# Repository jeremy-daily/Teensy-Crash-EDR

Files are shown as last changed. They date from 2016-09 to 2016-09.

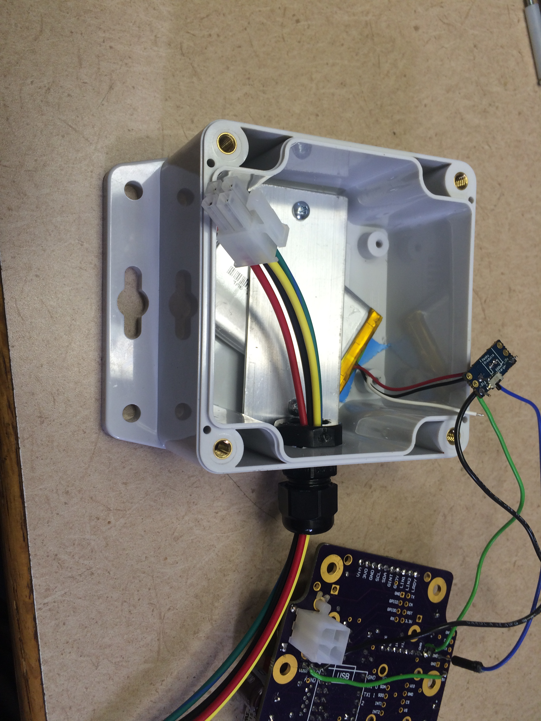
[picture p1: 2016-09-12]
docs/images/2016-09-09 13.49.59.jpg

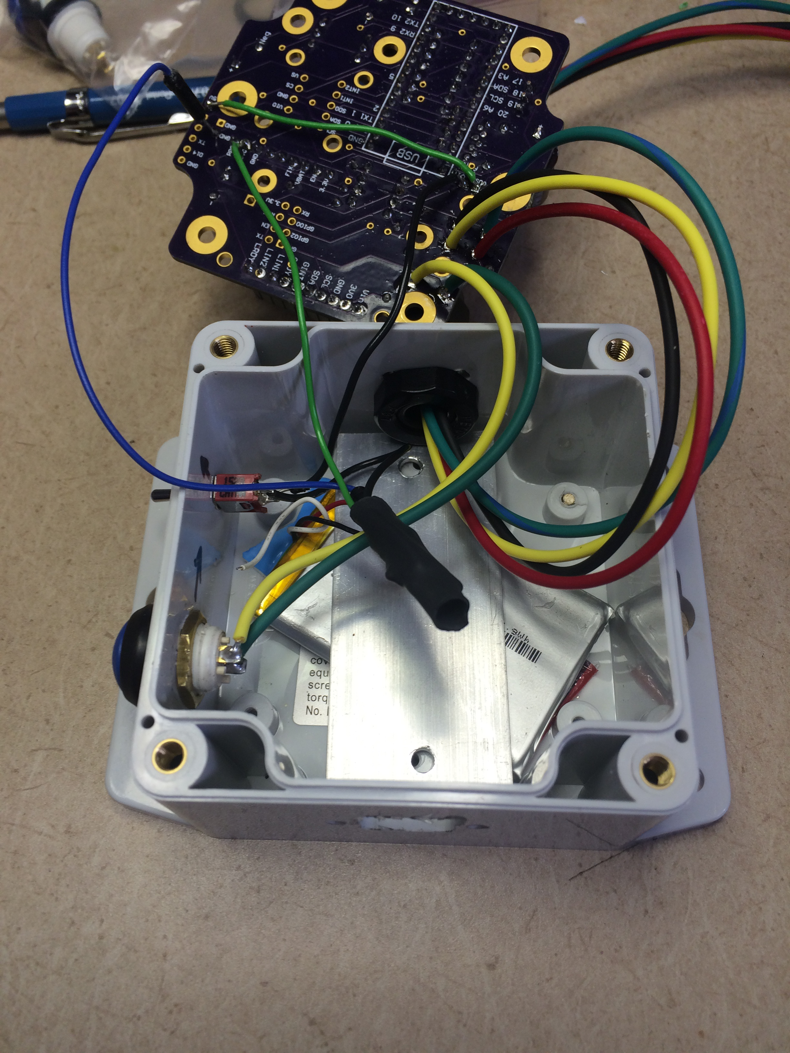
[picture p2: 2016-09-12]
docs/images/2016-09-09 15.58.58.jpg

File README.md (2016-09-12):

# Teensy-Crash-EDR
A Teensy 3.2 based through hole project that includes CAN, SD, GPS, Wireless, and Accelerometers.

CAUTION: This device is not intended to be used on public roadways. Connecting this device to a CAN bus may affect the operation of a vehicle or piece ofe equipment. If you decide to use the device and any code or derivatives, then anything bad that happens is your fault. Please use these resources responsibly.

The project website is https://jeremy-daily.github.io/Teensy-Crash-EDR/

## Project Purpose
The goal of this project is to design and share an open source data acquisition device that can be used for vehicle crash testing. The crash tests
considered are typically done at crash reconstruction conferences or trainig events where law enforcement and private crash investigators
gather to witness a crash and solidify their understanding of the dynamics involved with such an event. 

Additionally, a light version (the one without the sensors) is designed to be used in training on Controller Area Networks and J1939.

## Hardware Features
 * Microprocessor: Teensy 3.2 32-bit ARM-Cortex M4 Arduino compatible microprocessor board
 * MicroSD Card for storage (Tested to log data at 4000Hz)
 * GPS: Adafruit Ultimate GPS capable of 10Hz update rates
 * High Speed CAN (1Mbps) capable of processing 100% bus load
 * Real Time Clock
 * High G Tri-axial accelerometer (+/- 200G)
 * Low G Tri-axial Accelerometer
 * Tri-axial Rate Gyro
 * Tri-axial Magnetometer
 * Battery Powered (Charges with USB)
 * Wi-Fi Capable (Internet of Things)
 * 7-36 VDC input with reverse polarity protection
 * Open source design and easily obtainable parts (See Hardware and Schematics directory)
 * Low cost
 * All through hole parts so it can be easily hand soldered.

## Learning to Write Software
The idea of this project is to enable students to start from the beginning and succeed with little or no previous experience with writing code for embedded processors.
There are a couple of prerequisites: 
 1. Arduino software (the code was developed and tested with version 1.6.11)
 2. Teensyduino software, which is an extension of Arduino (the code was developed and tested and developed with v1.30)
 3. The SdFat Arduino library
The idea of the code development is to take examples that are close to the functionality of what you are interested in and adapt them to the hardware we have. As such, some of the examples and projects have different
programming styles. This is because those programs extend the code base from different sources. 

The following sections describe the functional and learning objectives of each of the enumerated examples in this repository. They example programs (sometimes called sketches) are intended to be used in sequence. The assignment is to extend
the functionality of each of the code bases to demonstrate the learning objectives. 

### Lesson 1: Blink
This is a basic program that helps the student understand the process of writing a program and uploading it to the processor to run. The objective is to be able to change the blink rate and see the result.

Assignment: Change the Blink Rate by using an elapsedMillis timer.
### Lesson 2: Receive CAN messages
Introduce the FlexCAN library and print the CAN messages to the serial output.

Assignment: Change the output format to be comma separated values
### Lesson 3: Real Time Clock
Add the time keeping libraries so CAN messages can be timestamped with the real time
 
Assignment: Add the microseconds to each real time stamp. (Hint: You can use an IntervalTimer to reset an elapsedMicros counter every second.)

### Lesson 4: Send Request Messages for J1939
Add the ability to broadcast request messages for different J1939 parameters. Some data is only available upon request.

Assignment: Send requests to different Destination Addresses. Add another PGN to request to the list.
### Lesson 5: Interpret Simple J1939 Messages
Using the J1939-71 or J1939-DA interpret some interesting messages, like wheel speed.

Assignment: Add interpreters for a couple other signals of interest (e.g. Engine RPM or Front Axle Speed)
### Lesson 6: Write data to an SD Card
Log all CAN traffic to an SD Card.

Assignment: Send request messages so the responses get logged.

## Future Work
### Lesson 7: Add GPS data to the SD log files (to be written)
 
### Lesson 8: Read Sensor Data (to be written)

### Lesson 9: Implement an Extended Kalman Filter (to be written)

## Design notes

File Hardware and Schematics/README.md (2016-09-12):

#Teensy 3.2 Based Crash EDR Hardware
This repository contains the information needed to understand how the device is built. The schematic provides the data needed to program 
the different input and output pins. The Bill of Materials is comprehsive in that it includes the parts for the circuit card assembly as well as the additional parts.
##Errata
 1. The 5V0 net and Vin need to be connected. This must be done by soldering an extra jumper wire between those pins. This modification is required for CAN to work.
 2. The Adafruit Ultimate GPS module has a 3.3V regulator and can provide power to the board if it is installed. However, the 3.3V line from the GPS headers is not connected, so it needs to have a jumper connected.
 3. The A14 voltage monitor is not connected, so R4 and R5 are not needed. Alternatively, they could be connected by hand. However, this feature is not that interesting.
 4. The silkscreen on the power and CAN entry cables have CANH and CANL backwards. In other words, the yellow CANH wire should be soldered to the bottom side into the CANH labeled hole. This only applied to the Rev2 boards.
## Minimum Assembly
For interfacing with CAN and creating a CAN logger to work with cars and trucks, you do not need the following:
 * 9-DOF IMU breakout board
 * 200G Triaxial Accelerometer
 * ESP8266 Wifi
 * Battery and Battery Charger
 
## Assembly Notes
 * Mount the voltage regulator on the bottom of the board.
 * Use long pinned female headers for the 7 holes hear the USB port on the Teensy 3.2. This enables a battery charger to be placed in line with the Teensy 3.2 under the board.
 * The 9-DOF board needs to be mounted on the bottom to ensure clearance for the USB cable.
 * The values of the electrolytic capacitors can be anywhere from 22uF to 400uF.
 * The four wires that go out of the box should be soldered to the bottom of the board. It is recommended that this be one of the last steps.
 * Be sure to tap the M3 holes in the Bud Box so the brass standoffs don't snap off when tightening. 
 
### Other Notes
 * The Wireless module is untested as of September 2016. Please let me know if this works.
 * The accelerometers (9DOF and High-G) are also untested. Please let me know if they work.

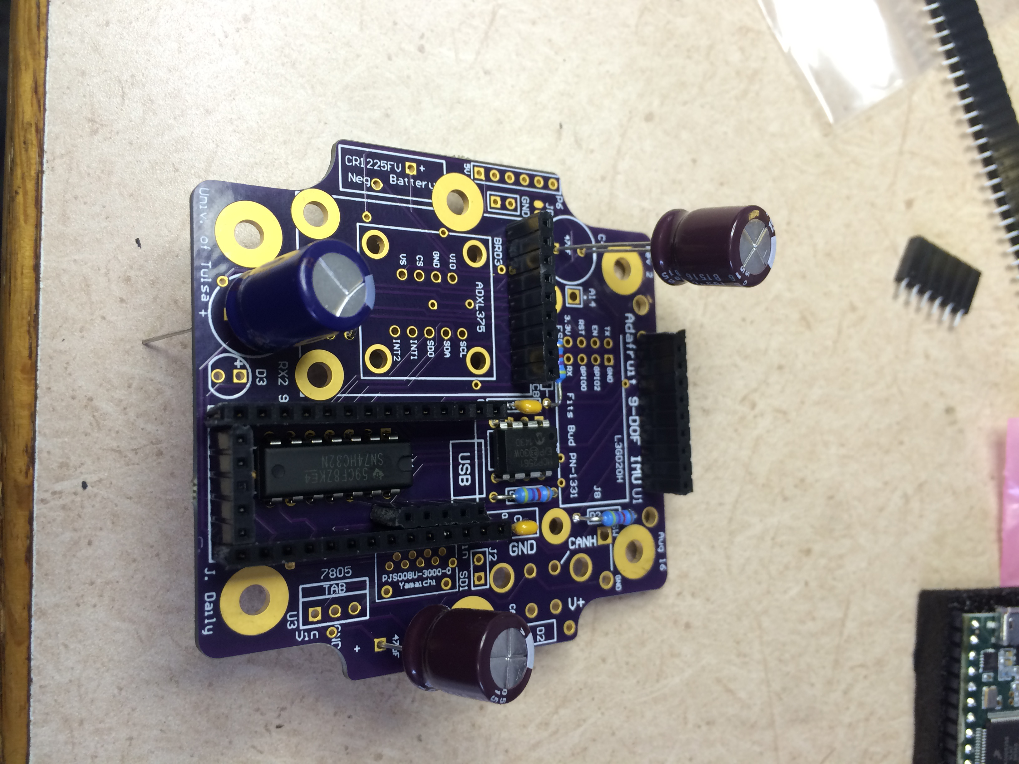
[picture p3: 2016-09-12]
docs/images/2016-09-08 16.24.32.jpg

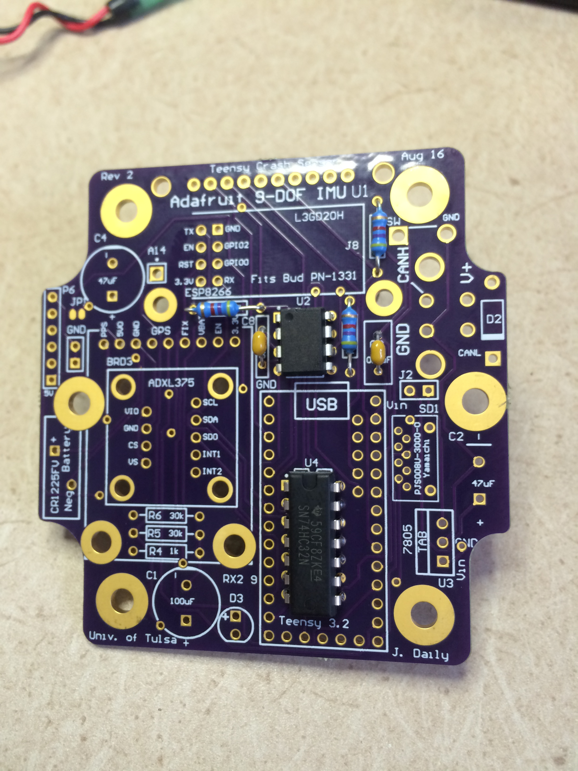
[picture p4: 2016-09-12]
docs/images/2016-09-08 16.00.48.jpg

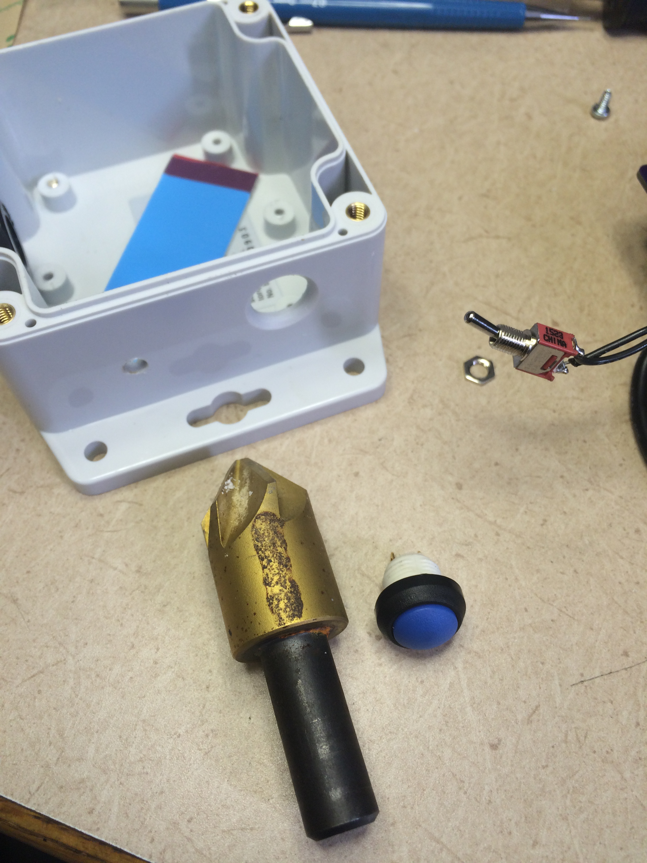
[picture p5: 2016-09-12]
docs/images/2016-09-09 14.00.34.jpg

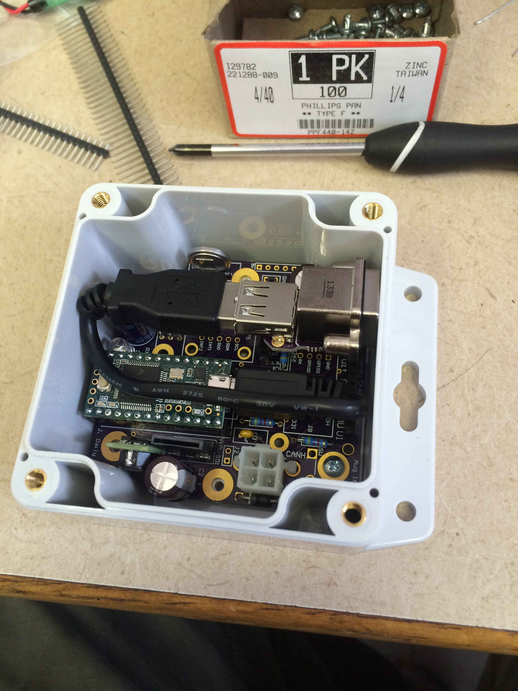
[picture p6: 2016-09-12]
docs/images/2016-09-08 16.52.31.jpg

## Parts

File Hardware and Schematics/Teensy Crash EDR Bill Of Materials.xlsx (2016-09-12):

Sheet: Top Level Assembly
Qty | Designator | Description | Manufacturer | Manufacturer Part Number | Supplier | Supplier Part Number | Unit Cost | Total Cost
1 | CCA | Teensy Crash Sensor Circuit Card Assembly | Self Assembled |  | See BOM |  | $38.97 | $38.97
1 | Cable1 | 6 inch Micro USB cable | StarTech | UUSBHAUB6 | Amazon | B003YKX6WM | $2.79 | $2.79
1 | Battery | 3.7V 1100mAh 432770 Lithium Polymer Li-Po Rechargeable Battery For DIY Mp3 MP4 MP5 GPS | Ofeely | 432770 | Amazon | B016ZU9C70 | $12.99 | $12.99
1 | Foam | 1/16" White Double Sided Acrylic Adhesive Polyethylene Foam Tape With Blue Poly Liner | Mr. Tape | Unknown | Amazon | B01H3ZULM6 | $0.07 | $0.07
1 | Sdcard | Samsung 16GB PRO Class 10 Micro SDHC Card with Adapter up to 90MB/s | Samsung | Unknown | Amazon | MB-MG16EA/AM | $10.99 | $10.99
1 | Wire,Blk | Automotive Primary Wire GXL-20, Cond: 7/28 (units are in feet) | Allied Wire and Cable | GXL-20 | awcwire.com | GXL-20 Black | $0.20 | $0.20
1 | Wire,Grn | Automotive Primary Wire GXL-20, Cond: 7/28 (units are in feet) | Allied Wire and Cable | GXL-20 | awcwire.com | GXL-20 Green | $0.20 | $0.20
1 | Wire,Red | Automotive Primary Wire GXL-20, Cond: 7/28 (units are in feet) | Allied Wire and Cable | GXL-20 | awcwire.com | GXL-20 Red | $0.20 | $0.20
1 | Wire,Yel | Automotive Primary Wire GXL-20, Cond: 7/28 (units are in feet) | Allied Wire and Cable | GXL-20 | awcwire.com | GXL-20 Yellow | $0.20 | $0.20
1 | USB2 | USB - A Receptacle Connector 4 Position Through Hole, Right Angle, Horizontal | On shore Technology | USB-A1HSW6 | Digikey | ED2989-ND | $0.48 | $0.48
0 | BRD2 (alt) | Adafruit 9-DOF IMU Breakout - L3GD20H + LSM303 PRODUCT ID: 1714 | Adafruit Industries LLC | 1714 | Digi-Key | 1528-1029-ND | $19.95 | $0.00
1 | GPS | Adafruit ultimate GPS breakout board | Adafruit Industries LLC | 746 | Digi-Key | 1528-1153-ND | $39.95 | $39.95
0 | ADXL375 (alt) | Analog Devices Accelerometer Evaluation Board | Analog Devices Inc. | EVAL-ADXL375Z | Digi-Key | EVAL-ADXL375Z-ND | $37.50 | $0.00
1 | Holder | 1/16" x 1" x 3" Aluminum strap with holes for the Battery Holder | Self cut and drilled | Unknown | McMaster-Carr | 8975K196 | $0.20 | $0.20
0 | HolderScrews | Pan Head Phillips Screw for Sheet Metal Zinc-Plated Steel, Number 4 Size, 5/16" Length | McMaster-Carr | 90190A107 | McMaster-Carr | 90190A107 | $0.02 | $0.00
2 | HolderScrews (alt) | Thread-Cutting Screw for Metal & Plastic (Type F) Pan Head Phillips, Zinc-Plated Steel, 4-40 Thread, 1/4" Long | McMaster-Carr | 90087A106 | McMaster-Carr | 90087A106 | $0.07 | $0.13
4 | PCB screw | Thread-Cutting Screw for Metal & Plastic (Type F) Pan Head Phillips, Zinc-Plated Steel, 4-40 Thread, 1/2" Long | McMaster-Carr | 90087A108 | McMaster-Carr | 90087A108 | $0.07 | $0.29
0 | PCB screw (alt) | Pan Head Phillips Screw for Sheet Metal Zinc-Plated Steel, Number 4 Size, 1/2" Length | McMaster-Carr | 90190A110 | McMaster-Carr | 90190A110 | $0.02 | $0.00
4 | ADXL Screw | Zinc-Plated Steel Pan Head Phillips Machine Screw 2-56 Thread, 5/16" Length | McMaster-Carr | 90272A078 | McMaster-Carr | 90272A078 | $0.03 | $0.13
6 | BoardScrew | Zinc-Plated Steel Pan Head Phillips Machine Screw 2-56 Thread, 5/8" Length | McMaster-Carr | 90272A083 | McMaster-Carr | 90272A083 | $0.09 | $0.52
0 | Nut1 | Low-Strength Steel Nylon-Insert Locknut Zinc-Plated, 2-56 Thread Size, 1/4" Wide, 9/64" High | McMaster-Carr | 90631A003 | McMaster-Carr | 90631A003 | $0.03 | $0.00
10 | Nut1 (alt) | Low-Strength Steel Thin Nylon-Insert Locknut Zinc-Plated, 2-56 Thread, 1/4" Wide, 7/64" High | McMaster-Carr | 90633A004 | McMaster-Carr | 90633A004 | $0.08 | $0.79
2 | USBScrews | Black-Oxide Finish Pan Head Phillips Machine Screw 18-8 Stainless Steel, 4-40 Thread, 3/8" Length | McMaster-Carr | 91249A108 | McMaster-Carr | 91249A108 | $0.04 | $0.08
4 | Spacer3 | Nylon Unthreaded Spacers 3/16" OD, 1/8" Length, for Number 2 Screw Size | McMaster-Carr | 94639A701 | McMaster-Carr | 94639A701 | $0.07 | $0.28
4 | Spacer1 | Nylon Unthreaded Spacers 3/16" OD, 1/4" Length, for Number 4 Screw Size | McMaster-Carr | 94639A706 | McMaster-Carr | 94639A706 | $0.08 | $0.30
6 | Spacer2 | Nylon Unthreaded Spacers 3/16" OD, 7/16" Length, for Number 2 Screw Size | McMaster-Carr | 94639A711 | McMaster-Carr | 94639A711 | $0.08 | $0.49
1 | ADXLPins | 64 Position Receptacle Connector 0.100" (2.54mm) Through Hole Gold | Mill-Max | 311-43-164-41-001000 | Mouser | 575-31143164 (http://www.mouser.com/Search/ProductDetail.aspx) | $5.34 | $5.34
1 | BRD2 | Multiple Function Sensor Development Tools L3GD20H + LSM303 IMU Breakout | Adafruit | 1714 | Mouser | 485-1714 | $19.95 | $19.95
1 | PSW | Power Switch Toggle Switches Solder Lug Slvr SP Off-None-On TS | TE Connectivity | TMS6T3B1M1QE (http://www.mouser.com/Search/ProductDetail.aspx) | Mouser | 506-TMS6T3B1M1QE | $5.19 | $5.19
2 | Headers | Headers & Wire Housings FULL STICK HDR/36POS | 3M | 929834-01-36-RK | Mouser | 517-929834-01-36-RK | $1.58 | $3.16
1 | TeensyPins, 5Pos | Tall Headers & Wire Housings .100 STR 5 PIN .235-.410 | 3M | 929834-03-05-RK (http://www.mouser.com/ProductDetail/3M-Electronic-Solutions-Division/929834-03-05-RK/) | Mouser | 517-929834-03-05-RK (http://www.mouser.com/ProductDetail/3M-Electronic-Solutions-Division/929834-03-05-RK/) | $0.66 | $0.66
1 | TeensyPins | Tall Headers & Wire Housings .100 STR 36 PIN .235-.410 | 3M | 929834-03-36-RK | Mouser | 517-929834-03-36-RK | $2.26 | $2.26
0 | TeensyXTAL | 32.768kHz ±20ppm Crystal 12.5pF 35 kOhm -20°C ~ 70°C Through Hole Cylindrical Can, Radial | Citizen Finedevice Co Ltd | CFS-20632768DZFB | Digi-Key | 300-1002-ND | $0.24 | $0.00
1 | TeensyXTAL (alt) | 32.768kHz ±20ppm Crystal 12.5pF 35 kOhm -20°C ~ 70°C Through Hole Cylindrical Can, Radial | Citizen Finedevice Co Ltd | CFS206-32.768KEZB-U | Mouser | 695-CFS206-327KEZB-U | $0.24 | $0.24
1 | USB1 | USB Connectors RUGGED USB TYPE B RIGHT ANGLE | Amphenol Commercial (http://www.mouser.com/amphenolcommercial/) | MUSB-D111-30 | Mouser | 523-MUSBD11130 | $9.59 | $9.59
4 | Socket | Molex Mini-Fit Jr Crimp Socket | Molex | 39-00-0060 | Mouser | 538-39-00-0060 | $0.24 | $0.96
1 | Recpt | Molex 4 ckt RCPT Housing | Molex | 39-01-2040 | Mouser | 538-39-01-2040 | $0.27 | $0.27
1 | Encl | Enclosures, Boxes, & Cases 3.23 x 3.15 x 2.17in Clear Lid | Bud Industries | PN-1331-CMB | Mouser | 563-PN-1331-CMB | $12.70 | $12.70
0 | USB2 (alt) | USB Connectors TYPE A R/A RCPT ASSY THRU HOLE | TE Connectivity / AMP (http://www.mouser.com/teampconnectors/) | 292303-3 | Mouser | 571-292303-3 | $1.21 | $0.00
1 | ADXL375 | Analog Devices Accelerometer Evaluation Board | Analog Devices | EVAL-ADXL375Z | Mouser | 584-EVAL-ADXL375Z | $37.50 | $37.50
0 | Battery (alt) | Battery Packs 3.7V 1320 mAh 61.0 x 37.5 x 5.95mm | Renata (http://www.mouser.com/renata/) | ICP543759PMT | Mouser | 614-ICP543759PMT | $31.54 | $0.00
1 | DeutschRecept | Automotive Connectors HD Series 9 Pin Plug | Amphenol SINE Systems | AHD16-9-1939S | Mouser | 654-AHD16-9-1939S | $8.87 | $8.87
4 | CrimpSockets | Automotive Connectors TERM 16 SOCKET 20-16AWG | Amphenol SINE Systems | AT62-201-16141 | Mouser | 654-AT62-201-16141 | $1.01 | $4.04
0 | Headers (alt) | 32 pin breakaway strips for Teensy GPS and IMU | Wurth Electronics | 61303211121 | Mouser | 710-61303211121 | $2.08 | $0.00
1 | CG | Liquid tight cord grip with 1/4 NPT threads | Heyco | M4516 | Mouser | 836-M4516 | $0.65 | $0.65
1 | SW | Push Button Momentary Switch | ITW Switches | 48-1-RB-N-BL-B (http://www.mouser.com/ProductDetail/ITW-Switches/48-1-RB-N-BL-B/) | Mouser | 850-48-1-RB-N-BL-B (http://www.mouser.com/ProductDetail/ITW-Switches/48-1-RB-N-BL-B/) | $9.02 | $9.02
1 | USBPCB | USB PCB Board | OSHPark | 9OxT4ywZ | OSHPark | https://oshpark.com/shared_projects/9OxT4ywZ | $1.00 | $1.00
1 | Teensy | 32 Bit Arduino-Compatible Microcontroller | PJRC | TEENSY32 | OSHPark | Teensy3.2 | $17.80 | $17.80
1 | Charger | STBC08 High-Current LiPo Battery Charger | Pesky Products | Unknown | Tinde.com | Unknown | $11.95 | $11.95
0 | Teensy (alt) | Teensy 32-bit Microcontroller With Pins | PJRC | TEENSY32_PINS | www.prjc.com | TEENSY32_PINS | $22.80 | $0.00
 |  |  |  |  |  |  | Total | $261.38

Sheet: Printed Circuit Board Parts
Comment | Description | Designators | Req'd. (Y/N) | Qty. | Manufacturer | Manufacturer Part Number | Supplier | Supplier Part Number 1 | Supplier Price | Total Price
ADXL Socket HEADER | 32 pin breakaway strips | ADXL | N | 1 | Mill-Max | 310-13-132-41-001000 | Mouser | 575-113132 | $2.08 | $2.08
ADXL Pin HEADER (alt) | 64 Pos Breakaway strips | ADXL | N | 0 | Mill-Max | 350-10-164-00-006000 | Mouser | 575-643506 | $8.15 | $0.00
CR1225FV-LF | Coin Cell Battery 3V 2-PIN VERT 48mAh 12.5 x 2.5mm | Batt1 | Y | 1 | Renata | CR1225FV-LF | Mouser | 614-CR1225FV-LF | $1.41 | $1.41
Socket Headers | 3M 929 Series 0.100" pitch single row breakable female socket header (36 pos) | BRD1, BRD2, BRD3, GPS | Y | 2 | 3M | 929974-01-36-RK | Mouser | 517-929974-01-36-RK | $1.63 | $3.26
100uF | CAP ALUM 100UF 20% 63V RADIAL | C1, C2 | Y | 1 | Panasonic | EEU-FC1J101 | Digi-Key | P10343-ND | $1.08 | $1.08
47uF | CAP ALUM 47UF 20% 63V RADIAL | C2, C4 | Y | 2 | Panasonic | EEU-FC1J470B | Mouser | 667-EEU-FC1J470B | $0.58 | $1.16
0.1uF | Multilayer Ceramic Capacitors MLCC - Leaded 50volts 0.1uF 10% X7R | C3, C8 | Y | 2 | AVX | SR215C104KAA | Mouser | 581-SR215C104K | $0.20 | $0.40
STPS2150 | Schottky Diodes & Rectifiers 2.0 Amp 150 Volt | D2 | Y | 1 | STMicroelectronics | STPS2150 | Mouser | 511-STPS2150 | $0.80 | $0.80
Red LED | LED RED DIFFUSED 0805 SMD | D3 | Y | 1 | Cree, Inc. (http://www.mouser.com/cree/) | C503B-RCN-CW0Z0AA1 | Mouser | 941-C503BRCNCW0Z0AA1 | $0.27 | $0.27
4 Pos Mini-Fit Jr. | CONN HEADER 4POS 4.2MM VERT TIN | J1 | Y | 1 | Molex, LLC | 39299042 | Mouser | 538-39-29-9042 | $0.66 | $0.66
ESP8266 (alt) | DIYmall Esp8266 Serial Wifi Wireless Transceiver Module Esp-01 | J8 | N | 0 | DIYMall | ESP-01 | Amazon | B00O34AGSU | $5.95 | $0.00
ESP8266 | Sparkfun ESP8266 Module (WRL-13678) | J8 | N | 1 | SparkFun Electronics | WRL-13678 | Digi-Key | 1568-1235-ND | $6.95 | $6.95
Printed Circuit Board | Teensy Crash EDR Printed Circuit Board | PCB | Y | 1 | OSH Park | https://oshpark.com/shared_projects/iA9z0hF5 | OSH Park | Teensy Crash EDR Board | $13.62 | $13.62
4.7k | RES 4.7K OHM 1/4W 5% CARBON FILM | R1, R2, R3 | Y | 3 | KOA Speer | MF1/4DCT52R4701F | Mouser | 660-MF1/4DCT52R4701F | $0.12 | $0.36
1.5k | RES 4.7K OHM 1/4W 5% CARBON FILM | R4 | Y | 1 | KOA Speer | MF1/4DCT52R1001F | Mouser | 660-MF1/4DCT52R1001F | $0.12 | $0.12
1.5k | RES 30K OHM 1/4W 5% CARBON FILM | R5, R6 | Y | 2 | KOA Speer | MF1/4DCT52R3002F | Mouser | 660-MF1/4DCT52R3002F | $0.12 | $0.24
microSD | Memory Card Connectors MicroSD Card Conn Ver Dip Mnt Manual | SD1 | Y | 1 | Yamaichi Electronics | PJS008U-3000-0 | Mouser | 945-PJS008U-3000-0 | $0.87 | $0.87
MCP2562-E/P | High-Speed CAN Transceiver, 8-Pin PDIP, Extended Temperature | U2 | Y | 1 | Microchip Technology (https://octopart-clicks.com/click/altium?sku=1439745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) | MCP2562-E/P (https://octopart-clicks.com/click/altium?sku=1439745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) | Digi-Key | MCP2562-E/P-ND (https://octopart-clicks.com/click/altium?sku=1439745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) | $0.93 | $0.93
OKI-78SR | 5V DC/DC Converter (7805 replacement) | U3 | Y | 1 | Murata Power Solutions Inc. (https://octopart-clicks.com/click/altium?manufacturer=Murata%20Power%20Solutions%20Inc.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) | OKI-78SR-5/1.5-W36-C (https://octopart-clicks.com/click/altium?manufacturer=Murata%20Power%20Solutions%20Inc.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) | Mouser | 580-OKI78SR5/1.5W36C | $4.30 | $4.30
74ACT32PC | Quad 2-Input OR Gate, 14-Pin PDIP, Commercial Grade | U4 | Y | 1 | Texas Instruments | SN74HC32N (http://www.mouser.com/ProductDetail/Texas-Instruments/SN74HC32N/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) | Mouser | 595-SN74HC32N (http://www.mouser.com/ProductDetail/Texas-Instruments/SN74HC32N/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) | $0.46 | $0.46
 |  |  |  |  |  |  |  |  | Total | $38.97

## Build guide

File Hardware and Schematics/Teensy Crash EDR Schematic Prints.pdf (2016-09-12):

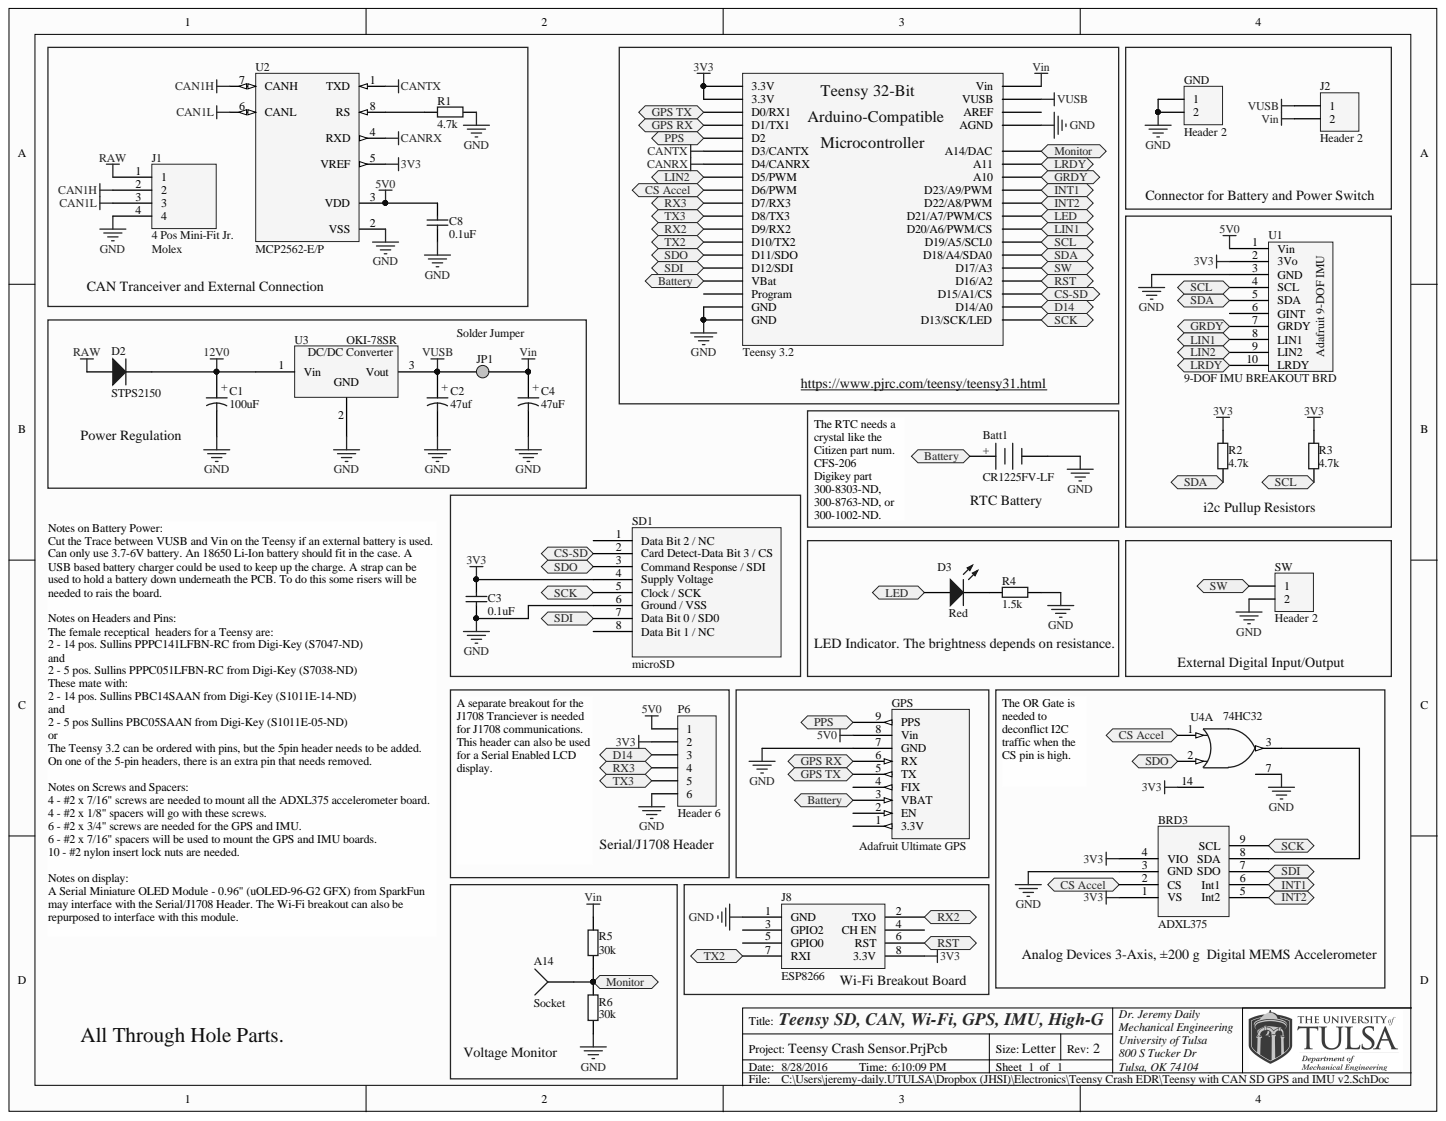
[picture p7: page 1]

Connector for Battery and Power Switch

4 Pos Mini-Fit Jr.
Molex

CAN Tranceiver and External Connection

https://www.pjrc.com/teensy/teensy31.html

Data Bit 2 / NC 1
Card Detect-Data Bit 3 / CS 2
Command Response / SDI 3
Supply Voltage 4
Clock / SCK 5
Ground / VSS 6
Data Bit 0 / SD0 7
Data Bit 1 / NC 8

Notes on Battery Power:
Cut the Trace between VUSB and Vin on the Teensy if an external battery is used.
Can only use 3.7-6V battery. An 18650 Li-Ion battery should fit in the case. A
USB based battery charger could be used to keep up the charge. A strap can be
used to hold a battery down underneath the PCB. To do this some risers will be
needed to rais the board.

Notes on Headers and Pins:
The female receptical headers for a Teensy are:
2 - 14 pos. Sullins PPPC141LFBN-RC from Digi-Key (S7047-ND)
and
2 - 5 pos. Sullins PPPC051LFBN-RC from Digi-Key (S7038-ND)
These mate with:
2 - 14 pos. Sullins PBC14SAAN from Digi-Key (S1011E-14-ND)
2 - 5 pos Sullins PBC05SAAN from Digi-Key (S1011E-05-ND)
The Teensy 3.2 can be ordered with pins, but the 5pin header needs to be added.
On one of the 5-pin headers, there is an extra pin that needs removed.

LED Indicator. The brightness depends on resistance.

External Digital Input/Output

A separate breakout for the
J1708 Tranciever is needed
for J1708 communications.
This header can also be used
for a Serial Enabled LCD
display.

The OR Gate is
needed to
deconflict I2C
traffic when the
CS pin is high.

Notes on Screws and Spacers:
4 - #2 x 7/16" screws are needed to mount all the ADXL375 accelerometer board.
4 - #2 x 1/8" spacers will go with these screws.
6 - #2 x 3/4" screws are needed for the GPS and IMU.
6 - #2 x 7/16" spacers will be used to mount the GPS and IMU boards.
10 - #2 nylon insert lock nuts are needed.

Notes on display:
A Serial Miniature OLED Module - 0.96" (uOLED-96-G2 GFX) from SparkFun
may interface with the Serial/J1708 Header. The Wi-Fi breakout can also be
repurposed to interface with this module.

Analog Devices 3-Axis, ±200 g Digital MEMS Accelerometer

Wi-Fi Breakout Board

Teensy SD, CAN, Wi-Fi, GPS, IMU, High-G Title: | Dr. Jeremy Daily Mechanical Engineering University of Tulsa 800 S Tucker Dr Tulsa, OK 74104

All Through Hole Parts.

Project: Teensy Crash Sensor.PrjPcb | Size: Letter | Rev: 2
Date: 8/28/2016 Time: 6:10:09 PM | Sheet 1 of 1

C:\Users\jeremy-daily.UTULSA\Dropbox (JHSI)\Electronics\Teensy Crash EDR\Teensy with CAN SD GPS and IMU v2.SchDoc

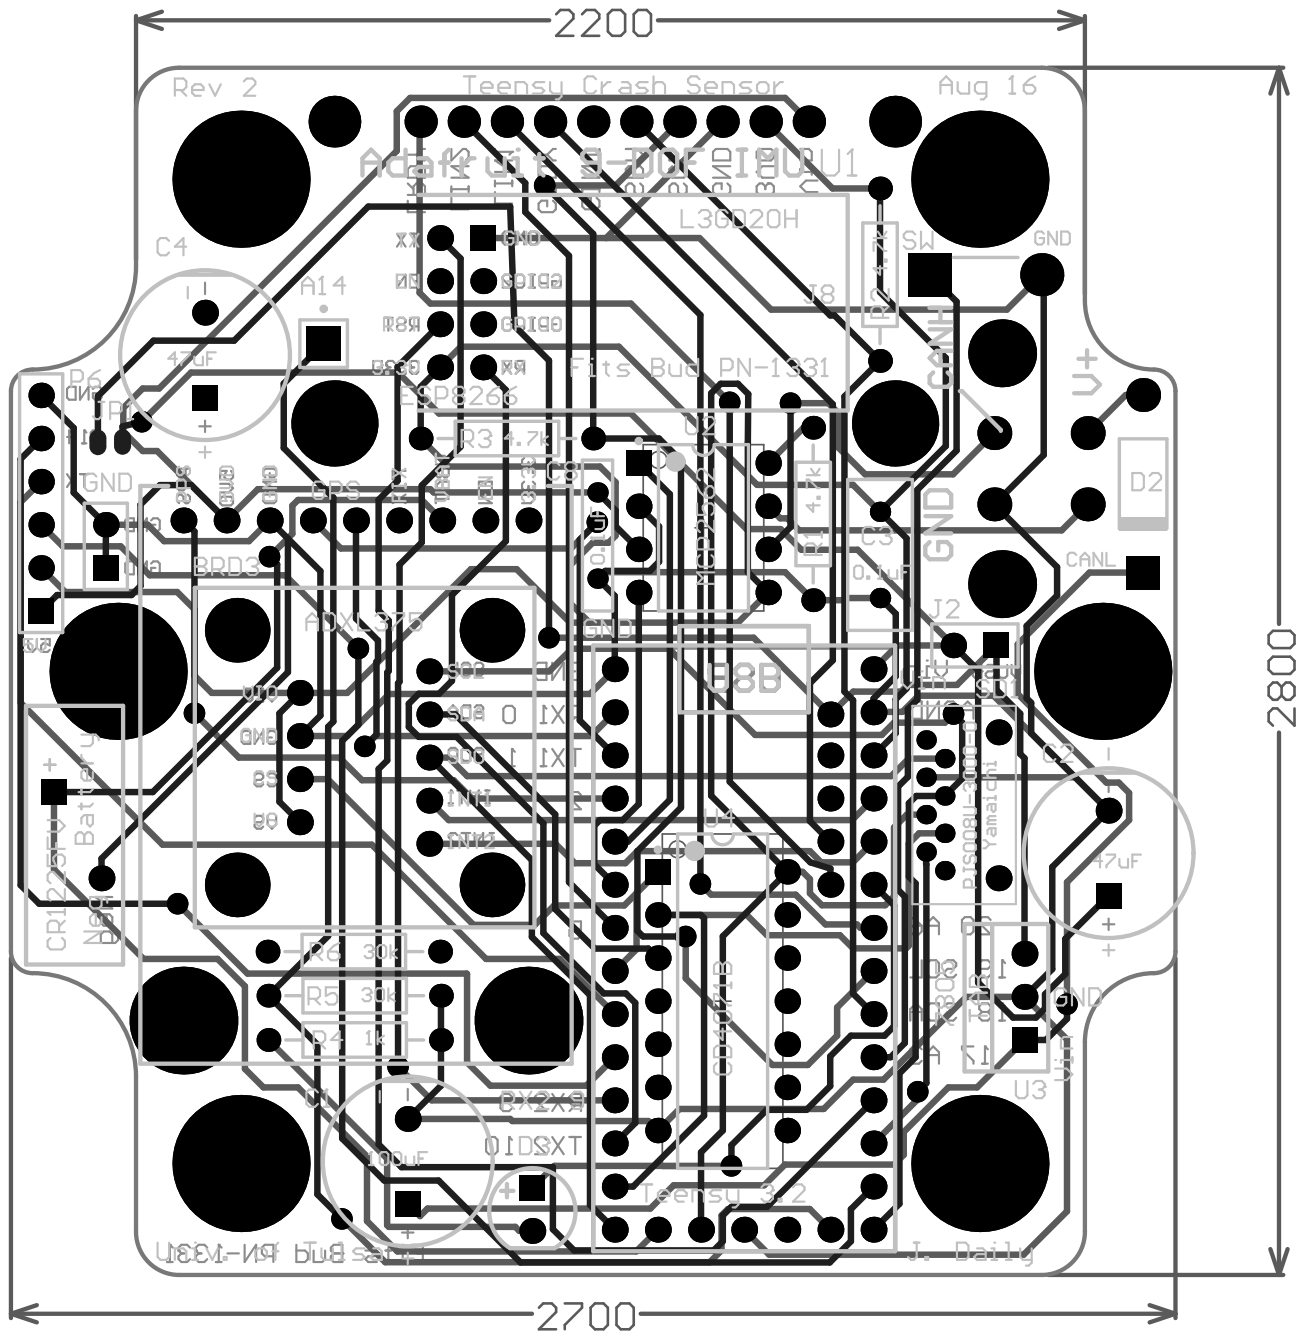
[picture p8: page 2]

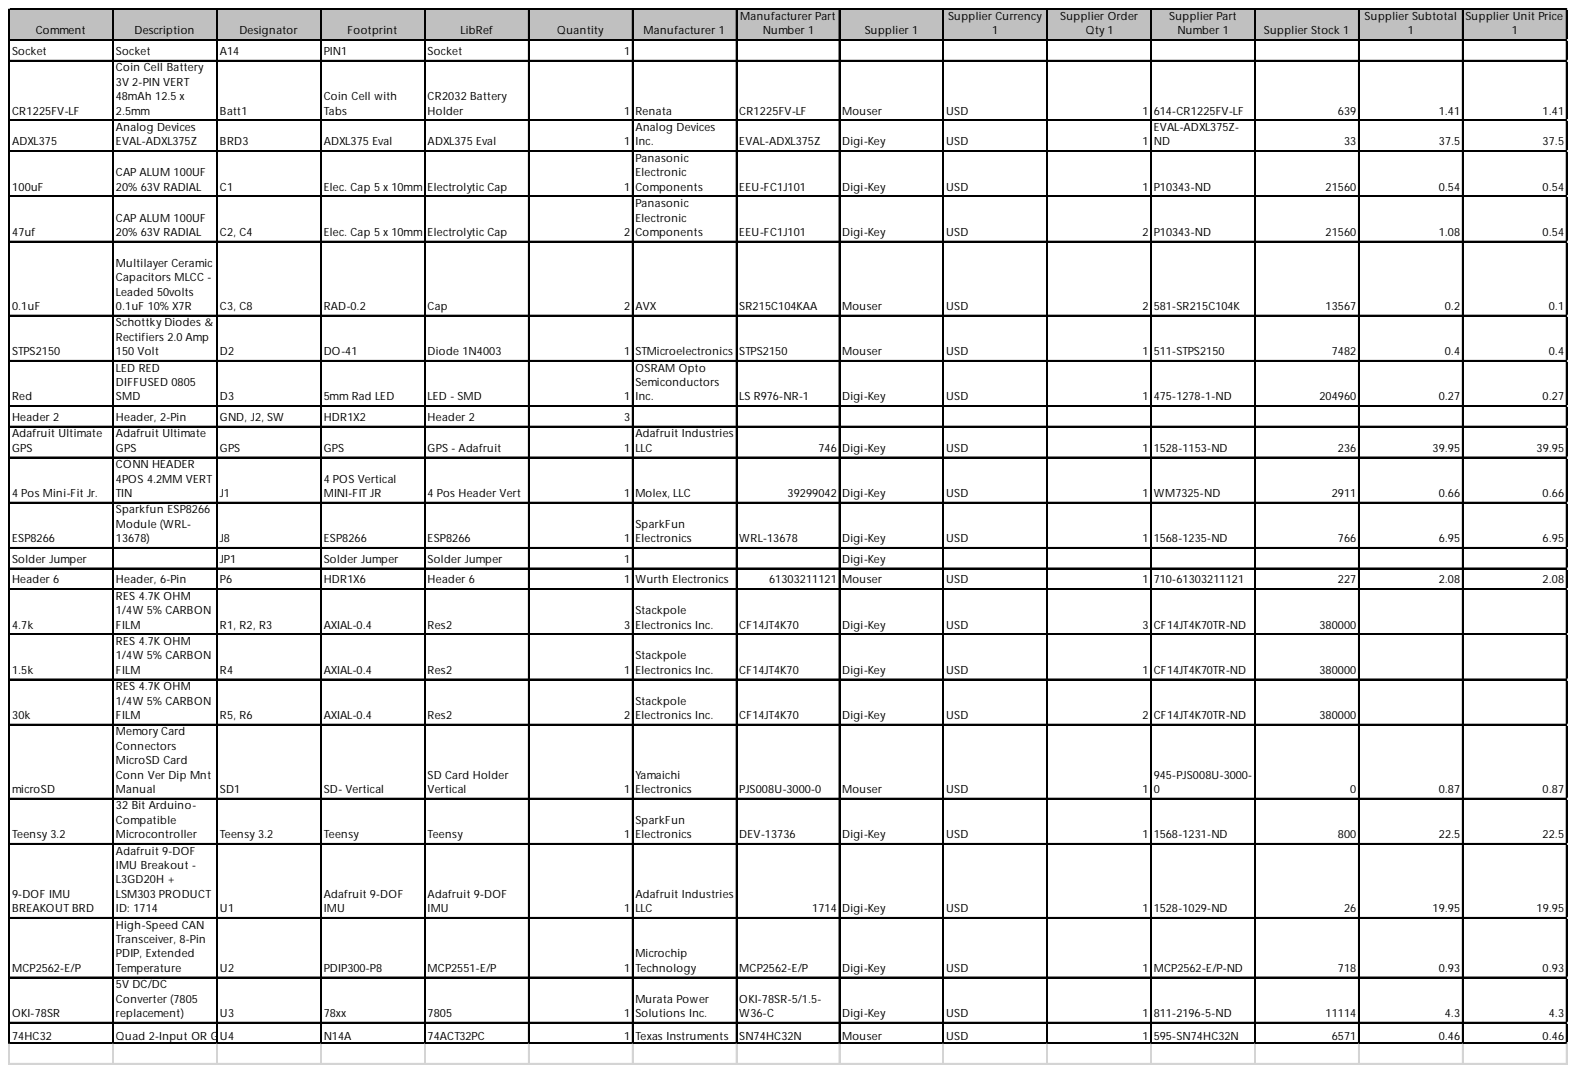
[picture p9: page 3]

Comment | Description | Designator | Footprint | LibRef | Quantity | Manufacturer 1 | Manufacturer Part Number 1 | Supplier 1 | Supplier Currency 1 | Supplier Order Qty 1 | Supplier Part Number 1 | Supplier Stock 1 | Supplier Subtotal 1 | Supplier Unit Price 1

Socket | Socket | A14 | PIN1 | Socket | 1
CR1225FV-LF | Coin Cell Battery 3V 2-PIN VERT 48mAh 12.5 x 2.5mm | Batt1 | Coin Cell with Tabs | CR2032 Battery Holder | 1 | Renata | CR1225FV-LF | Mouser | USD | 1 | 614-CR1225FV-LF | 639 | 1.41 | 1.41

ADXL375 | Analog Devices EVAL-ADXL375Z | BRD3 | ADXL375 Eval | ADXL375 Eval | 1 | Analog Devices Inc. | EVAL-ADXL375Z | Digi-Key | USD | 1 | EVAL-ADXL375Z-ND | 33 | 37.5 | 37.5

100uF | CAP ALUM 100UF 20% 63V RADIAL | C1 | Elec. Cap 5 x 10mm | Electrolytic Cap | 1 | Panasonic Electronic Components | EEU-FC1J101 | Digi-Key | USD | 1 | P10343-ND | 21560 | 0.54 | 0.54

47uf | CAP ALUM 100UF 20% 63V RADIAL | C2, C4 | Elec. Cap 5 x 10mm | Electrolytic Cap | 2 | Panasonic Electronic Components | EEU-FC1J101 | Digi-Key | USD | 2 | P10343-ND | 21560 | 1.08 | 0.54

0.1uF | Multilayer Ceramic Capacitors MLCC -Leaded 50volts 0.1uF 10% X7R | C3, C8 | RAD-0.2 | Cap | 2 | AVX | SR215C104KAA | Mouser | USD | 2 | 581-SR215C104K | 13567 | 0.2 | 0.1

STPS2150 | Schottky Diodes & Rectifiers 2.0 Amp 150 Volt | D2 | DO-41 | Diode 1N4003 | 1 | STMicroelectronics | STPS2150 | Mouser | USD | 1 | 511-STPS2150 | 7482 | 0.4 | 0.4

Red | LED RED DIFFUSED 0805 SMD | D3 | 5mm Rad LED | LED - SMD | 1 | OSRAM Opto Semiconductors Inc. | LS R976-NR-1 | Digi-Key | USD | 1 | 475-1278-1-ND | 204960 | 0.27 | 0.27

Header 2 | Header, 2-Pin | GND, J2, SW | HDR1X2 | Header 2 | 3
Adafruit Ultimate GPS | Adafruit Ultimate GPS | GPS | GPS | GPS - Adafruit | 1 | Adafruit Industries LLC | 746 | Digi-Key | USD | 1 | 1528-1153-ND | 236 | 39.95 | 39.95

4 Pos Mini-Fit Jr. | CONN HEADER 4POS 4.2MM VERT TIN | J1 | 4 POS Vertical MINI-FIT JR | 4 Pos Header Vert | 1 | Molex, LLC | 39299042 | Digi-Key | USD | 1 | WM7325-ND | 2911 | 0.66 | 0.66

ESP8266 | Sparkfun ESP8266 Module (WRL-13678) | J8 | ESP8266 | ESP8266 | 1 | SparkFun Electronics | WRL-13678 | Digi-Key | USD | 1 | 1568-1235-ND | 766 | 6.95 | 6.95

Solder Jumper | | JP1 | Solder Jumper | Solder Jumper | 1 | | | Digi-Key
Header 6 | Header, 6-Pin | P6 | HDR1X6 | Header 6 | 1 | Wurth Electronics | 61303211121 | Mouser | USD | 1 | 710-61303211121 | 227 | 2.08 | 2.08
4.7k | RES 4.7K OHM 1/4W 5% CARBON FILM | R1, R2, R3 | AXIAL-0.4 | Res2 | 3 | Stackpole Electronics Inc. | CF14JT4K70 | Digi-Key | USD | 3 | CF14JT4K70TR-ND | 380000

1.5k | RES 4.7K OHM 1/4W 5% CARBON FILM | R4 | AXIAL-0.4 | Res2 | 1 | Stackpole Electronics Inc. | CF14JT4K70 | Digi-Key | USD | 1 | CF14JT4K70TR-ND | 380000

30k | RES 4.7K OHM 1/4W 5% CARBON FILM | R5, R6 | AXIAL-0.4 | Res2 | 2 | Stackpole Electronics Inc. | CF14JT4K70 | Digi-Key | USD | 2 | CF14JT4K70TR-ND | 380000

microSD | Memory Card Connectors MicroSD Card Conn Ver Dip Mnt Manual | SD1 | SD- Vertical | SD Card Holder Vertical | 1 | Yamaichi Electronics | PJS008U-3000-0 | Mouser | USD | 1 | 945-PJS008U-3000-0 | 0 | 0.87 | 0.87

Teensy 3.2 | 32 Bit Arduino-Compatible Microcontroller | Teensy 3.2 | Teensy | Teensy | 1 | SparkFun Electronics | DEV-13736 | Digi-Key | USD | 1 | 1568-1231-ND | 800 | 22.5 | 22.5

9-DOF IMU BREAKOUT BRD | Adafruit 9-DOF IMU Breakout -L3GD20H + LSM303 PRODUCT ID: 1714 | U1 | Adafruit 9-DOF IMU | Adafruit 9-DOF IMU | 1 | Adafruit Industries LLC | 1714 | Digi-Key | USD | 1 | 1528-1029-ND | 26 | 19.95 | 19.95

MCP2562-E/P | High-Speed CAN Transceiver, 8-Pin PDIP, Extended Temperature | U2 | PDIP300-P8 | MCP2551-E/P | 1 | Microchip Technology | MCP2562-E/P | Digi-Key | USD | 1 | MCP2562-E/P-ND | 718 | 0.93 | 0.93

OKI-78SR | 5V DC/DC Converter (7805 replacement) | U3 | 78xx | 7805 | 1 | Murata Power Solutions Inc. | OKI-78SR-5/1.5-W36-C | Digi-Key | USD | 1 | 811-2196-5-ND | 11114 | 4.3 | 4.3

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

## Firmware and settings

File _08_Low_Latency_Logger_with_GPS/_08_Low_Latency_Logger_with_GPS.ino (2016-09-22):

/**
 * This program logs data to a binary file.  Functions are included
 * to convert the binary file to a csv text file.
 *
 * Samples are logged at regular intervals.  The maximum logging rate
 * depends on the quality of your SD card and the time required to
 * read sensor data.  This example has been tested at 500 Hz with
 * good SD card on an Uno.  4000 HZ is possible on a Due.
 *
 * If your SD card has a long write latency, it may be necessary to use
 * slower sample rates.  Using a Mega Arduino helps overcome latency
 * problems since 13 512 byte buffers will be used.
 *
 * Data is written to the file using a SD multiple block write command.
 */
// log file base name.  Must be five characters or less.
#define FILE_BASE_NAME "DATA"
 
#include <SPI.h>
#include <SdFat.h>
#include <SdFatUtil.h>
#include <FlexCAN.h>
#include "kinetis_flexcan.h"
#include <TimeLib.h>
#include <TinyGPS.h>

TimeElements tm;
time_t GPStime = 0;   
//------------------------------------------------------------------------------
// User data functions.  Modify these functions for your data items.
#include "UserDataType.h"  // Edit this include file to change data_t.

FlexCAN CANbus(250000);
static CAN_message_t rxmsg;

IntervalTimer oneSecondReset;
elapsedMicros microsecondsPerSecond;
elapsedMillis buttonPressTimer;
elapsedMillis GPSsampleTimer;

TinyGPS gps;

boolean gpsEncoded;

void resetMicros() {
  microsecondsPerSecond = 0; //reset the timer
}

// Acquire a data record.
void acquireCANData(data_t* data) {
  data->timeStamp = now();
  data->usec = uint32_t(microsecondsPerSecond);
  data->type = 0;
  data->ID = ( 0x00 << 24 ) | rxmsg.id; // let the first byte in the ID data word to be 0 if this is GPS data.
  data->DLC = rxmsg.len;
  memset(data->dataField,0xFF,8);
  for (uint8_t i = 0; i < rxmsg.len; i++){
    data->dataField[i] = rxmsg.buf[i];  
  }
}



void acquireGPSData(data_t* data) {
  int GPSyear;
  byte GPSmonth, GPSday, GPShour, GPSminute, GPSsecond, GPShundredths;
  unsigned long GPSage;
  do{
    if (Serial1.available()) gps.encode(Serial1.read());
    gps.crack_datetime(&GPSyear, &GPSmonth, &GPSday, &GPShour, &GPSminute, &GPSsecond, &GPShundredths, &GPSage);
    Serial.print(GPShour);
    Serial.print(":");
    Serial.print(GPSminute);
    Serial.print(":");
    Serial.print(GPSsecond);
    Serial.print(" ");
    Serial.print(GPSday);
    Serial.print("-");
    Serial.print(GPSmonth);
    Serial.print("-");
    Serial.print(GPSyear); 
    Serial.println(); 
    tm.Second = GPSsecond;
    tm.Minute = GPSminute;
    tm.Hour = GPShour;
    tm.Day = GPSday;
    tm.Month = GPSmonth;
    tm.Year = GPSyear-1970;
    GPStime = makeTime(tm);
  } while (GPStime < 1471842557); //
  
  int32_t latitude;
  int32_t longitude;
  uint32_t fix_age;
  gps.get_position(&latitude,&longitude,&fix_age);
  data->timeStamp = now();
  data->usec = latitude; //Millionths of a degree
  data->type = 1;
  data->ID = GPStime; 
  data->DLC = longitude;
  data->dataField[0] = (0xFF00 & gps.speed())>>8;
  data->dataField[1] = 0xFF & gps.speed();
  data->dataField[2] = (0xFF00 & gps.course()) >> 8;
  data->dataField[3] = 0xFF & gps.course();
  data->dataField[4] = (0xFF00 & gps.altitude()) >> 8;
  data->dataField[5] = 0xFF & gps.altitude();
  data->dataField[6] = gps.hdop();
  data->dataField[7] = gps.satellites();
}

// Print a data record.
void printData(Print* pr, data_t* data) {
  int type = data->type;
  if (type == 0 || type ==1 ){
    time_t recordTime = data->timeStamp;
    char timeString[100];
    sprintf(timeString,"%04d-%02d-%02d %02d:%02d:%02d.%06d\t",year(recordTime),month(recordTime),day(recordTime),hour(recordTime),minute(recordTime),second(recordTime),data->usec);
    pr->print(timeString);
    
    sprintf(timeString,"%10d.%06d",data->timeStamp,data->usec);
    pr->print(timeString);
    
    
    char IDString[11];
    sprintf(IDString,"\t%08X\t",data->ID);
    pr->print(IDString);
    pr->print(data->DLC);
    for (int i = 0; i < 8; i++) {
      char entry[4];
      sprintf(entry,"\t%02X",data->dataField[i]);
      pr->print(entry);
    }
    pr->println();
  }
  
}

// Print data header.
void printHeader(Print* pr) {
  pr->print(F("YYYY-MM-DD HH:MM:SS.usec,"));
  pr->print(F("Unix timeStamp,"));
  pr->print(F("ID,"));
  pr->print(F("DLC"));
  for (uint8_t i = 0; i < 8; i++) {
    pr->print(F(",B"));
    pr->print(i);
  }
  pr->println();
}
//==============================================================================
// Start of configuration constants.
//==============================================================================
//Interval between data records in microseconds.
const uint32_t LOG_INTERVAL_USEC = 250;
//------------------------------------------------------------------------------
// Pin definitions.
//
// SD chip select pin.
const uint8_t SD_CS_PIN = 15;
//
// Digital pin to indicate an error, set to -1 if not used.
// The led blinks for fatal errors. The led goes on solid for SD write
// overrun errors and logging continues.
const uint8_t ERROR_LED_PIN = 21;

const uint8_t BUTTON_PIN = 17;
//------------------------------------------------------------------------------
// File definitions.
//
// Maximum file size in blocks.
// The program creates a contiguous file with FILE_BLOCK_COUNT 512 byte blocks.
// This file is flash erased using special SD commands.  The file will be
// truncated if logging is stopped early.
//const uint32_t FILE_BLOCK_COUNT = 256000;
//const uint32_t FILE_BLOCK_COUNT = 2097152; //1 GB
const uint32_t FILE_BLOCK_COUNT = 8388607; //4 GB - 512



//------------------------------------------------------------------------------
// Buffer definitions.
//
// The logger will use SdFat's buffer plus BUFFER_BLOCK_COUNT additional
// buffers.
//
#ifndef RAMEND
// Assume ARM. Use total of nine 512 byte buffers.
const uint8_t BUFFER_BLOCK_COUNT = 8;
//
#elif RAMEND < 0X8FF
#error Too little SRAM
//
#elif RAMEND < 0X10FF
// Use total of two 512 byte buffers.
const uint8_t BUFFER_BLOCK_COUNT = 1;
//
#elif RAMEND < 0X20FF
// Use total of five 512 byte buffers.
const uint8_t BUFFER_BLOCK_COUNT = 4;
//
#else  // RAMEND
// Use total of 13 512 byte buffers.
const uint8_t BUFFER_BLOCK_COUNT = 12;
#endif  // RAMEND
//==============================================================================
// End of configuration constants.
//==============================================================================
// Temporary log file.  Will be deleted if a reset or power failure occurs.
#define TMP_FILE_NAME "tmp_log.bin"

// Size of file base name.  Must not be larger than six.
const uint8_t BASE_NAME_SIZE = sizeof(FILE_BASE_NAME) - 1;

SdFat sd;

SdBaseFile binFile;

char binName[13] = FILE_BASE_NAME "00.bin";

// Number of data records in a block.
const uint16_t DATA_DIM = (512 - 4)/sizeof(data_t);

//Compute fill so block size is 512 bytes.  FILL_DIM may be zero.
const uint16_t FILL_DIM = 512 - 4 - DATA_DIM*sizeof(data_t);

struct block_t {
  uint16_t count;
  uint16_t overrun;
  data_t data[DATA_DIM];
  uint8_t fill[FILL_DIM];
};

//------------------------------------------------------------------------------
/*
 * User provided date time callback function.
 * See SdFile::dateTimeCallback() for usage.
 */
void dateTime(uint16_t* FATdate, uint16_t* FATtime) {
  // User gets date and time from GPS or real-time
  // clock in real callback function

  // return date using FAT_DATE macro to format fields
  *FATdate = FAT_DATE(year(), month(), day());

  // return time using FAT_TIME macro to format fields
  *FATtime = FAT_TIME(hour(), minute(), second());
}


const uint8_t QUEUE_DIM = BUFFER_BLOCK_COUNT + 2;

block_t* emptyQueue[QUEUE_DIM];
uint8_t emptyHead;
uint8_t emptyTail;

block_t* fullQueue[QUEUE_DIM];
uint8_t fullHead;
uint8_t fullTail;

// Advance queue index.
inline uint8_t queueNext(uint8_t ht) {
  return ht < (QUEUE_DIM - 1) ? ht + 1 : 0;
}
//==============================================================================
// Error messages stored in flash.
#define error(msg) errorFlash(F(msg))
//------------------------------------------------------------------------------
void errorFlash(const __FlashStringHelper* msg) {
  sd.errorPrint(msg);
  fatalBlink();
}
//------------------------------------------------------------------------------
//
void fatalBlink() {
  while (true) {
    if (ERROR_LED_PIN >= 0) {
      digitalWrite(ERROR_LED_PIN, HIGH);
      delay(80);
      digitalWrite(ERROR_LED_PIN, LOW);
      delay(80);
      
    }
  }
}
//==============================================================================
// Convert binary file to csv file.
void binaryToCsv() {
  uint8_t lastPct = 0;
  block_t block;
  uint32_t t0 = millis();
  uint32_t syncCluster = 0;
  SdFile csvFile;
  char csvName[13];

  if (!binFile.isOpen()) {
    Serial.println();
    Serial.println(F("No current binary file"));
    return;
  }
  binFile.rewind();
  // Create a new csvFile.
  strcpy(csvName, binName);
  strcpy(&csvName[BASE_NAME_SIZE + 3], "csv");

  if (!csvFile.open(csvName, O_WRITE | O_CREAT | O_TRUNC)) {
    error("open csvFile failed");
  }
  Serial.println();
  Serial.print(F("Writing: "));
  Serial.print(csvName);
  Serial.println(F(" - type any character to stop"));
  printHeader(&csvFile);
  uint32_t tPct = millis();
  while (!Serial.available() && binFile.read(&block, 512) == 512) {
     if (Serial1.available()) gps.encode(Serial1.read());
  
    uint16_t i;
    if (block.count == 0) {
      break;
    }
    if (block.overrun) {
      csvFile.print(F("OVERRUN,"));
      csvFile.println(block.overrun);
    }
    for (i = 0; i < block.count; i++) {
      printData(&csvFile, &block.data[i]);
    }
    if (csvFile.curCluster() != syncCluster) {
      csvFile.sync();
      syncCluster = csvFile.curCluster();
    }
    if ((millis() - tPct) > 1000) {
      uint8_t pct = binFile.curPosition()/(binFile.fileSize()/100);
      if (pct != lastPct) {
        tPct = millis();
        lastPct = pct;
        Serial.print(pct, DEC);
        Serial.println('%');
      }
    }
    if (Serial.available()) {
      break;
    }
  }
  csvFile.close();
  Serial.print(F("Done: "));
  Serial.print(0.001*(millis() - t0));
  Serial.println(F(" Seconds"));
}
//------------------------------------------------------------------------------
// read data file and check for overruns
void checkOverrun() {
  bool headerPrinted = false;
  block_t block;
  uint32_t bgnBlock, endBlock;
  uint32_t bn = 0;

  if (!binFile.isOpen()) {
    Serial.println();
    Serial.println(F("No current binary file"));
    return;
  }
  if (!binFile.contiguousRange(&bgnBlock, &endBlock)) {
    error("contiguousRange failed");
  }
  binFile.rewind();
  Serial.println();
  Serial.println(F("Checking overrun errors - type any character to stop"));
  while (binFile.read(&block, 512) == 512) {
    if (Serial1.available()) gps.encode(Serial1.read());
  
    if (block.count == 0) {
      break;
    }
    if (block.overrun) {
      if (!headerPrinted) {
        Serial.println();
        Serial.println(F("Overruns:"));
        Serial.println(F("fileBlockNumber,sdBlockNumber,overrunCount"));
        headerPrinted = true;
      }
      Serial.print(bn);
      Serial.print(',');
      Serial.print(bgnBlock + bn);
      Serial.print(',');
      Serial.println(block.overrun);
    }
    bn++;
  }
  if (!headerPrinted) {
    Serial.println(F("No errors found"));
  } else {
    Serial.println(F("Done"));
  }
}
//------------------------------------------------------------------------------
// dump data file to Serial
void dumpData() {
  block_t block;
  if (!binFile.isOpen()) {
    Serial.println();
    Serial.println(F("No current binary file"));
    return;
  }
  binFile.rewind();
  Serial.println();
  Serial.println(F("Type any character to stop"));
  delay(100);
  printHeader(&Serial);
  while (!Serial.available() && binFile.read(&block , 512) == 512) {
    if (Serial1.available()) gps.encode(Serial1.read());
  
    if (block.count == 0) {
      break;
    }
    if (block.overrun) {
      Serial.print(F("OVERRUN,"));
      Serial.println(block.overrun);
    }
    for (uint32_t i = 0; i < block.count; i++) {
      printData(&Serial, &block.data[i]);
    }
  }
  Serial.println(F("Done"));
}
//------------------------------------------------------------------------------
// log data
// max number of blocks to erase per erase call
uint32_t const ERASE_SIZE = 262144L;
void logData() {
  uint32_t bgnBlock, endBlock;

  // Allocate extra buffer space.
  block_t block[BUFFER_BLOCK_COUNT];
  block_t* curBlock = 0;
  Serial.println();

  // Find unused file name.
  if (BASE_NAME_SIZE > 5) {
    error("FILE_BASE_NAME too long");
  }
  while (sd.exists(binName)) {
    if (binName[BASE_NAME_SIZE + 1] != '9') {
      binName[BASE_NAME_SIZE + 1]++;
    } else {
      binName[BASE_NAME_SIZE + 1] = '0';
      if (binName[BASE_NAME_SIZE] == '9') {
        error("Can't create file name");
      }
      binName[BASE_NAME_SIZE]++;
    }
  }
  // Delete old tmp file.
  if (sd.exists(TMP_FILE_NAME)) {
    Serial.println(F("Deleting tmp file"));
    if (!sd.remove(TMP_FILE_NAME)) {
      error("Can't remove tmp file");
    }
  }
  // Create new file.
  Serial.println(F("Creating new file"));
  binFile.close();
  if (!binFile.createContiguous(sd.vwd(),
                                TMP_FILE_NAME, 512 * FILE_BLOCK_COUNT)) {
    error("createContiguous failed");
  }
  // Get the address of the file on the SD.
  if (!binFile.contiguousRange(&bgnBlock, &endBlock)) {
    error("contiguousRange failed");
  }
  // Use SdFat's internal buffer.
  uint8_t* cache = (uint8_t*)sd.vol()->cacheClear();
  if (cache == 0) {
    error("cacheClear failed");
  }

  // Flash erase all data in the file.
  Serial.println(F("Erasing all data"));
  uint32_t bgnErase = bgnBlock;
  uint32_t endErase;
  while (bgnErase < endBlock) {
    endErase = bgnErase + ERASE_SIZE;
    if (endErase > endBlock) {
      endErase = endBlock;
    }
    if (!sd.card()->erase(bgnErase, endErase)) {
      error("erase failed");
    }
    bgnErase = endErase + 1;
  }
  // Start a multiple block write.
  if (!sd.card()->writeStart(bgnBlock, FILE_BLOCK_COUNT)) {
    error("writeBegin failed");
  }
  // Initialize queues.
  emptyHead = emptyTail = 0;
  fullHead = fullTail = 0;

  // Use SdFat buffer for one block.
  emptyQueue[emptyHead] = (block_t*)cache;
  emptyHead = queueNext(emptyHead);

  // Put rest of buffers in the empty queue.
  for (uint8_t i = 0; i < BUFFER_BLOCK_COUNT; i++) {
    emptyQueue[emptyHead] = &block[i];
    emptyHead = queueNext(emptyHead);
  }
  Serial.println(F("Logging - type any character to stop"));
  // Wait for Serial Idle.
  Serial.flush();
  delay(10);
  uint32_t bn = 0;
  uint32_t t0 = millis();
  uint32_t t1 = t0;
  uint32_t overrun = 0;
  uint32_t overrunTotal = 0;
  uint32_t count = 0;
  uint32_t maxLatency = 0;
  int32_t diff;
  // Start at a multiple of interval.
  uint32_t logTime = micros()/LOG_INTERVAL_USEC + 1;
  logTime *= LOG_INTERVAL_USEC;
  bool closeFile = false;
  digitalWrite(ERROR_LED_PIN,HIGH);
  while (1) {
     if (Serial1.available()) gps.encode(Serial1.read());
  
    // Time for next data record.
    //logTime += LOG_INTERVAL_USEC;
    if (Serial.available() || (!digitalRead(BUTTON_PIN) && buttonPressTimer>100) ) {
      closeFile = true;
      buttonPressTimer = 0;
    }

    if (closeFile) {
      if (curBlock != 0 && curBlock->count >= 0) {
        // Put buffer in full queue.
        fullQueue[fullHead] = curBlock;
        fullHead = queueNext(fullHead);
        curBlock = 0;
      }
    } 
    else {
      if (curBlock == 0 && emptyTail != emptyHead) {
        curBlock = emptyQueue[emptyTail];
        emptyTail = queueNext(emptyTail);
        curBlock->count = 0;
        curBlock->overrun = overrun;
        overrun = 0;
      }
//      do {
//        diff = logTime - micros();
//      } while(diff > 0);
//      if (diff < -10) {
//        error("LOG_INTERVAL_USEC too small");
//      }
      if (curBlock == 0) {
        overrun++;
      } else {
        if (CANbus.read(rxmsg)) acquireCANData(&curBlock->data[curBlock->count++]);
        if (Serial1.available()) {
          char q = Serial1.read();
          //Serial.print(q);
          gpsEncoded = gps.encode(q);
        }
        
        if (GPSsampleTimer >= 200){
          GPSsampleTimer = 0; 
          acquireGPSData(&curBlock->data[curBlock->count++]);
        }
        
        if (curBlock->count == DATA_DIM) {
          fullQueue[fullHead] = curBlock;
          fullHead = queueNext(fullHead);
          curBlock = 0;
        }
      }
    }

    if (fullHead == fullTail) {
      // Exit loop if done.
      if (closeFile) {
        break;
      }
    } else if (!sd.card()->isBusy()) {
      // Get address of block to write.
      block_t* pBlock = fullQueue[fullTail];
      fullTail = queueNext(fullTail);
      // Write block to SD.
      uint32_t usec = micros();
      if (!sd.card()->writeData((uint8_t*)pBlock)) {
        error("write data failed");
      }
      usec = micros() - usec;
      t1 = millis();
      if (usec > maxLatency) {
        maxLatency = usec;
      }
      count += pBlock->count;

      // Add overruns and possibly light LED.
      if (pBlock->overrun) {
        overrunTotal += pBlock->overrun;
        if (ERROR_LED_PIN >= 0) {
          digitalWrite(ERROR_LED_PIN, HIGH);
        }
      }
      // Move block to empty queue.
      emptyQueue[emptyHead] = pBlock;
      emptyHead = queueNext(emptyHead);
      bn++;
      if (bn == FILE_BLOCK_COUNT) {
        // File full so stop
        break;
      }
    }
  }
  if (!sd.card()->writeStop()) {
    error("writeStop failed");
  }
  // Truncate file if recording stopped early.
  if (bn != FILE_BLOCK_COUNT) {
    Serial.println(F("Truncating file"));
    if (!binFile.truncate(512L * bn)) {
      error("Can't truncate file");
    }
  }
  if (!binFile.rename(sd.vwd(), binName)) {
    error("Can't rename file");
  }
  Serial.print(F("File renamed: "));
  Serial.println(binName);
  Serial.print(F("Max block write usec: "));
  Serial.println(maxLatency);
  Serial.print(F("Record time sec: "));
  Serial.println(0.001*(t1 - t0), 3);
  Serial.print(F("Sample count: "));
  Serial.println(count);
  Serial.print(F("Samples/sec: "));
  Serial.println((1000.0)*count/(t1-t0));
  Serial.print(F("Overruns: "));
  Serial.println(overrunTotal);
  Serial.println(F("Done"));
}
//------------------------------------------------------------------------------

time_t getTeensy3Time()
{
  return Teensy3Clock.get();
}

void setup(void) {
  CANbus.begin();
  rxmsg.timeout = 0;

  pinMode(6,OUTPUT);
  digitalWrite(6,HIGH);
  pinMode(BUTTON_PIN,INPUT_PULLUP);
  
 pinMode(ERROR_LED_PIN, OUTPUT);
 
  Serial.begin(9600);
  digitalWrite(ERROR_LED_PIN,HIGH);
  delay(1000);
  digitalWrite(ERROR_LED_PIN,LOW);
  
  setSyncProvider(getTeensy3Time);
  if (timeStatus()!= timeSet) {
    Serial.println("Unable to sync with the RTC");
  } else {
    Serial.println("RTC has set the system time");
  }

  Serial.print("Starting GPS... ");
  //tft.println("Starting GPS");
  Serial1.begin(9600);
  delay(300);
  Serial1.println("$PMTK251,57600*2C"); //Set Baud Rate to 57600
  delay(100);
  Serial1.flush();
  Serial1.end();
  Serial.println("Setting GPS to 57600 baud... ");
  Serial1.begin(57600);
  //delay(300);
  Serial1.println("$PMTK251,57600*2C"); //Set Baud Rate to 57600

  Serial.println("Setting GPS to update at 5 Hz... ");
  Serial1.println("$PMTK220,200*2C"); //update at 5 Hz
  delay(100);
  Serial1.println("$PMTK300,200,0,0,0,0*2F"); //position fix update to 5 Hz
  for (int i = 0; i < 100; i++) {
    if (Serial1.available()) Serial.write(Serial1.read());
  }
  Serial.println("\nDone.");
  
  
  char timeString[22];
  time_t previousTime = now();
  while (now() - previousTime < 1) resetMicros();
  oneSecondReset.begin(resetMicros,1000000);
  
  sprintf(timeString,"%04d-%02d-%02d %02d:%02d:%02d.%06d",year(),month(),day(),hour(),minute(),second(),uint32_t(microsecondsPerSecond));
  Serial.println(timeString);
  
  Serial.print(F("FreeRam: "));
  Serial.println(FreeRam());
  Serial.print(F("Records/block: "));
  Serial.println(DATA_DIM);
  if (sizeof(block_t) != 512) {
    error("Invalid block size");
  }
  // initialize file system.
  if (!sd.begin(SD_CS_PIN, SPI_FULL_SPEED)) {
    sd.initErrorPrint();
    fatalBlink();
  }
  // set date time callback function
  SdFile::dateTimeCallback(dateTime);
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
void loop(void) {
  if (ERROR_LED_PIN >= 0) {
    digitalWrite(ERROR_LED_PIN, LOW);
  }
  
  // discard any input
  while (Serial.read() >= 0) {}
  
  Serial.println();
  Serial.println(F("type:"));
  Serial.println(F("c - convert file to csv"));
  Serial.println(F("d - dump data to Serial"));
  Serial.println(F("e - overrun error details"));
  Serial.println(F("r - record data"));

  while(!Serial.available() && digitalRead(BUTTON_PIN) )  if (Serial1.available()) gps.encode(Serial1.read());
  
  buttonPressTimer = 0;
  delay(50); //debounce
  char c;
  if (Serial.available()) c = tolower(Serial.read());
  while (Serial.read() >= 0);
  if (!digitalRead(BUTTON_PIN)) c = 'r';
  while (!digitalRead(BUTTON_PIN)){
    if (buttonPressTimer > 2000){
      c='c';
      break;
    }
  }
  
  if (c == 'c') {
    analogWrite(ERROR_LED_PIN,64);
    binaryToCsv();
    analogWrite(ERROR_LED_PIN,0);
  } else if (c == 'd') {
    dumpData();
  } else if (c == 'e') {
    checkOverrun();
  } else if (c == 'r') {
    logData();
  }  else if (!digitalRead(BUTTON_PIN)) {
     delay(500);
     if (!digitalRead(BUTTON_PIN)) logData();
  } else {
    Serial.println(F("Invalid entry"));
  }
  
  digitalWrite(ERROR_LED_PIN, LOW);
  
  while (!digitalRead(BUTTON_PIN)){
     if (Serial1.available()) gps.encode(Serial1.read());
  
    if (ERROR_LED_PIN >= 0) {
      digitalWrite(ERROR_LED_PIN, LOW);
    }
  }//Wait to release the button;
}

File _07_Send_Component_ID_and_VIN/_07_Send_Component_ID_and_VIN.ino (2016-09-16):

//Reading data from CAN and displaying it on a serial port
//Include the realtime clock functions inspired by the TimeTeensy3.ino example
//Add capability to send request messages


//Include the CAN libraries for the Teensy microprocessor
#include <FlexCAN.h>
#include <TimeLib.h>

char compID[100] = "TULSA*Teensy-Crash-EDR*Box*1";
char VIN[18] = "THIS IS MY VIN 12";

const uint16_t PGNRequestList[28] = {
  65261, // Cruise Control/Vehicle Speed Setup
  65214, // Electronic Engine Controller 4
  65259, // Component Identification
  65242, // Software Identification
  65244, // Idle Operation
  65260, // Vehicle Identification
  65255, // Vehicle Hours
  65253, // Engine Hours, Revolutions
  65257, // Fuel Consumption (Liquid)
  65256, // Vehicle Direction/Speed
  65254, // Time/Date
  65211, // Trip Fan Information
  65210, // Trip Distance Information
  65209, // Trip Fuel Information (Liquid)
  65207, // Engine Speed/Load Factor Information
  65206, // Trip Vehicle Speed/Cruise Distance Information
  65205, // Trip Shutdown Information
  65204, // Trip Time Information 1
  65200, // Trip Time Information 2
  65250, // Transmission Configuration
  65253, // Engine Hours, Revolutions
  65203, // Fuel Information (Liquid)
  65201, // ECU History
  65168, // Engine Torque History
  64981, // Electronic Engine Controller 5
  64978, // ECU Performance
  64965, // ECU Identification Information
  65165  // Vehicle Electrical Power #2
};

uint8_t pgnIndex = 0;

//Declare which pin is connected to the LED
//Use the Teensy Reference Card and the board schematics to determine the pin number
const int redLEDpin = 21;

//initiate the CAN library at 250kbps
FlexCAN CANbus(250000);

//Set up the CAN data structure
static CAN_message_t rxmsg;
static CAN_message_t txmsg;

//set up a counter for each received message
unsigned long int rxCount = 0;

//set up a timer to toggle the LEDs so the delay function isn't needed.
elapsedMillis LEDtoggleTimer;
elapsedMillis millisecondsPerSecond;
elapsedMillis requestTimer;
elapsedMillis requestSendTimer;

const int millisBetweenRequests = 1000;

//Keep track of the LED state
boolean ledState = true;


void setup() {
  // put your setup code here, to run once:

  //declare the LED Pin to be the output
  pinMode(redLEDpin,OUTPUT);
  digitalWrite(redLEDpin,ledState); //Turn on the LED
  
  //start the CAN access
  CANbus.begin();
  rxmsg.timeout = 0;
  txmsg.timeout = 0;
  txmsg.len = 8;
  txmsg.id = 0x18EA00F6; //Reqest PGN
  txmsg.ext = 1;
  
  //try to wait for the Serial bus to come up for 1 second
  delay(1000);
  Serial.println(F("Teensy 3.2 CAN Receive Test with Component ID."));
  
  
  //print a header
  Serial.print(F("     Count\t    micros\t  CAN ID\tDLC"));
  for (uint8_t i = 1; i<9;i++){ //label the byte columns according to J1939
    char byteDigits[4]; //declare a byte display array
    sprintf(byteDigits,"\tB%i",i);
    Serial.print(byteDigits); 
  }

}

void loop() {
  // put your main code here, to run repeatedly:

  while(CANbus.read(rxmsg)){
    rxCount++;
    
    uint32_t ID = rxmsg.id;
    uint8_t len = rxmsg.len;
    
    char timeCountIDandDLCdigits[50]; 
    sprintf(timeCountIDandDLCdigits,"%10i\t%10i\t%08X\t%1i",rxCount,micros(),ID,len);
   // Serial.print(timeCountIDandDLCdigits); 
      
    for (uint8_t i = 0; i<len;i++){ 
      char byteDigits[4]; 
      sprintf(byteDigits,"\t%02X",rxmsg.buf[i]);
 //     Serial.print(byteDigits); 
    }
 //Serial.println();

    if ((ID & 0x00FF0000) == 0x00EA0000){
        Serial.print("Request Message Received");

        char timeCountIDandDLCdigits[50]; 
        sprintf(timeCountIDandDLCdigits,"%10i\t%10i\t%08X\t%1i",rxCount,micros(),ID,len);
        Serial.print(timeCountIDandDLCdigits); 
          
        for (uint8_t i = 0; i<len;i++){ 
          char byteDigits[4]; 
          sprintf(byteDigits,"\t%02X",rxmsg.buf[i]);
          Serial.print(byteDigits); 
        }
        Serial.println();
 
        if (rxmsg.buf[0] == 0xEC && rxmsg.buf[1] == 0xFE){
          requestSendTimer = 0;
          sendVIN(VIN);
        }
//        else if (rxmsg.buf[0] == 0xEB && rxmsg.buf[1] == 0xFE){
//          requestSendTimer = 0;
//          sendComponentInfo(compID);
//        }
        
    }
  }

    
  
  if (LEDtoggleTimer >=100){
    LEDtoggleTimer = 0; //reset the timer
    ledState = !ledState; // Toggle values
    digitalWrite(redLEDpin,ledState);
  }

  if (requestTimer >= millisBetweenRequests) {
    requestTimer = 0;
    uint16_t pgnToRequest = PGNRequestList[pgnIndex];
    pgnIndex++;
    if (pgnIndex > sizeof(PGNRequestList) ) pgnIndex = 0;

    txmsg.ext = 1;
    txmsg.id = 0x18EA00F9; //request PGN
    txmsg.buf[0] = (pgnToRequest & 0x0000FF);
    txmsg.buf[1] = (pgnToRequest & 0x00FF00) >> 8 ;
    txmsg.buf[2] = (pgnToRequest & 0xFF0000) >> 16;
    txmsg.len = 3;
    CANbus.write(txmsg);
  }
  

}

void sendComponentInfo(char id[100])
{
       txmsg.ext = 1;
       txmsg.len = 8;
  
       Serial.print("Received Request for Component ID. Sending  ");
       for (int i = 0; i < 35;i++) Serial.print(id[i]);
       Serial.println();
       byte transport0[8] = {32,35,0,5,0xFF,0xEB,0xFE,0};
       byte transport1[8] = {1,id[0],id[1],id[2],id[3],id[4],id[5],id[6]};
       byte transport2[8] = {2,id[7],id[8],id[9],id[10],id[11],id[12],id[13]};
       byte transport3[8] = {3,id[14],id[15],id[16],id[17],id[18],id[19],id[20]};
       byte transport4[8] = {4,id[21],id[22],id[23],id[24],id[25],id[26],id[27]};
       byte transport5[8] = {5,id[28],id[29],id[30],id[31],id[32],id[33],id[34]};
       txmsg.id = 0x18ECFF18;
       for (int i = 0;i<8;i++) txmsg.buf[i]=transport0[i];
       CANbus.write(txmsg);
       delay(3);
       txmsg.id = 0x18EBFF18;
       for (int i = 0;i<8;i++) txmsg.buf[i]=transport1[i];
       CANbus.write(txmsg);
       delay(3);
       for (int i = 0;i<8;i++) txmsg.buf[i]=transport2[i];
       CANbus.write(txmsg);
       delay(3);
       for (int i = 0;i<8;i++) txmsg.buf[i]=transport3[i];
       CANbus.write(txmsg);
       delay(3);
       for (int i = 0;i<8;i++) txmsg.buf[i]=transport4[i];
       CANbus.write(txmsg); 
       delay(3);
       for (int i = 0;i<8;i++) txmsg.buf[i]=transport5[i];
       if (CANbus.write(txmsg)) Serial.print("Sent Last Message");
       
}
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

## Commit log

2016-09-09 Initial Sketches to get started with Teensy
2016-09-10 Added a real time clock to the CAN logger
    Adapted the Teensy Examples to ad RTC. Also uses an elapsedMillis
    construct to get milliseconds per second.
2016-09-12 Added Readmes and Hardware
    Getting all the assignments ready for a class
    [Teensy Crash EDR Bill Of Materials.xlsx, Teensy Crash EDR v3 for Bud PN-1331 PCB Board.PcbDoc, Teensy Crash EDR v3.PrjPcb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]
2016-09-12 Added Assembly Photos to Docs
2016-09-12 Added another picture of the battery
2016-09-14 Day 1 end of class
    This is the code with all the tweaks from the crash.
    [_03_Add_RealtimeClock.ino, _04_Send_Request_Messages.ino, _05_Interpret_Simple_J1939_Messages.ino]
2016-09-15 Included a working sketch to plot Wheel Speed
    This is the answer for #5
2016-09-16 Added a couple RP1210 Files
    Hello World and the DG Sample Source
2016-09-16 Added the ability to send VIN
    Adapt the example code to include the ability to send VIN. Still needs
    to work out the timing issues.
    [_07_Send_Component_ID_and_VIN.ino]
